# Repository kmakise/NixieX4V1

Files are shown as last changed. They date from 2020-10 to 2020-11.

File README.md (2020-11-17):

# NixieX4V1
四位辉光钟 演示视频：https://www.bilibili.com/video/BV1ni4y1E7YB

# 电源
 12V-5V TPS54331  12V-170V MAX1771

# 控制
 MCU：STM32F103C8T6 REG：74HC595 T：ALJ01 Nixie：QS18-12
 
# 图片




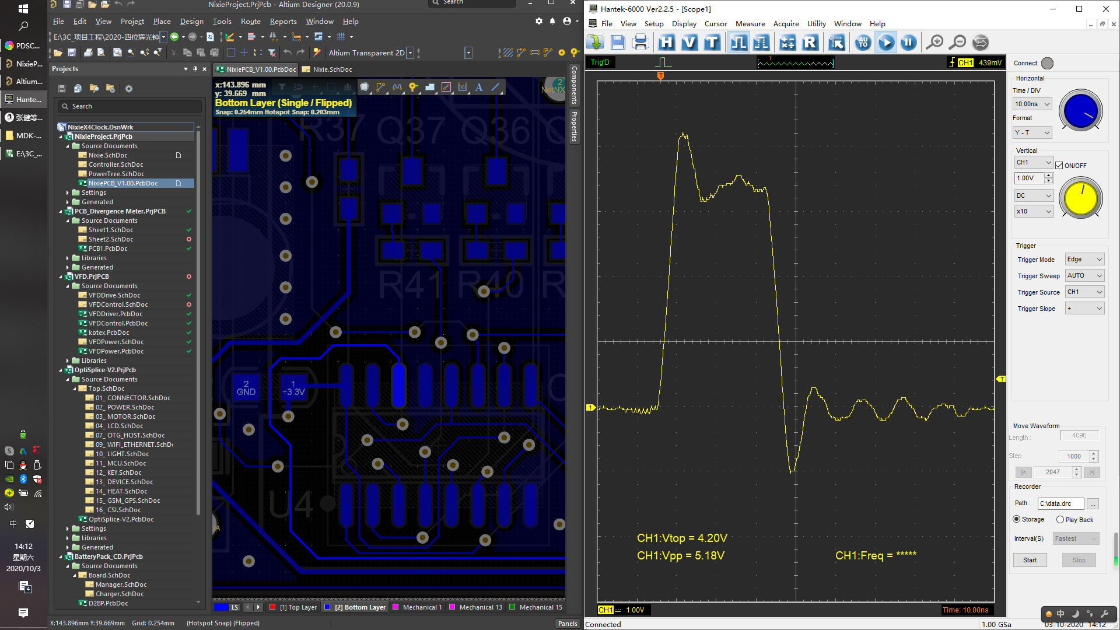
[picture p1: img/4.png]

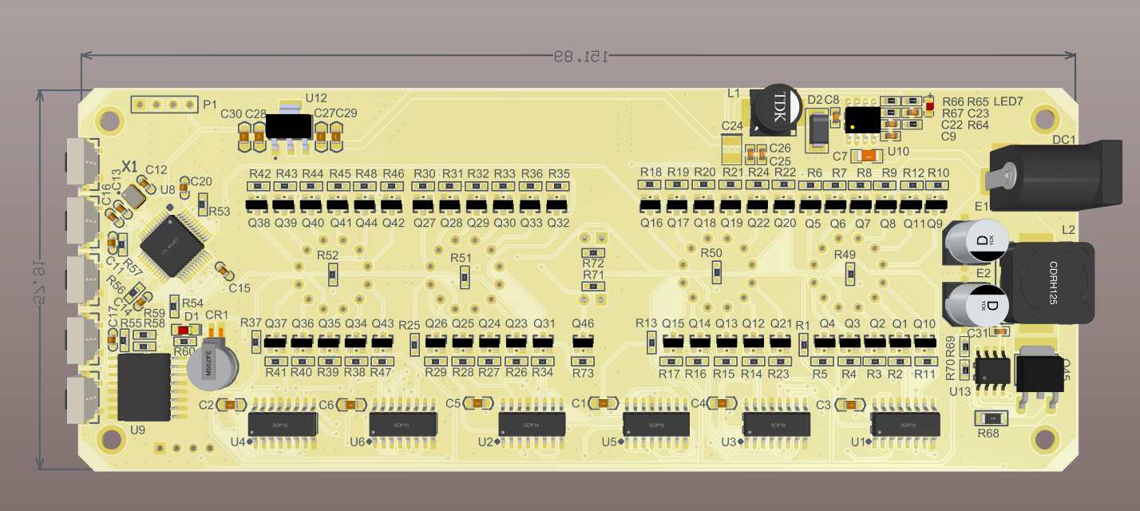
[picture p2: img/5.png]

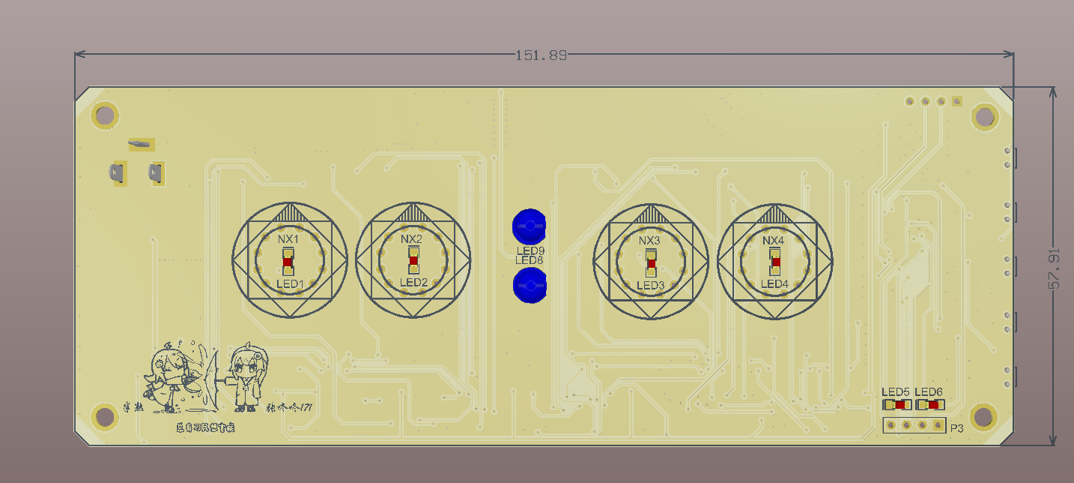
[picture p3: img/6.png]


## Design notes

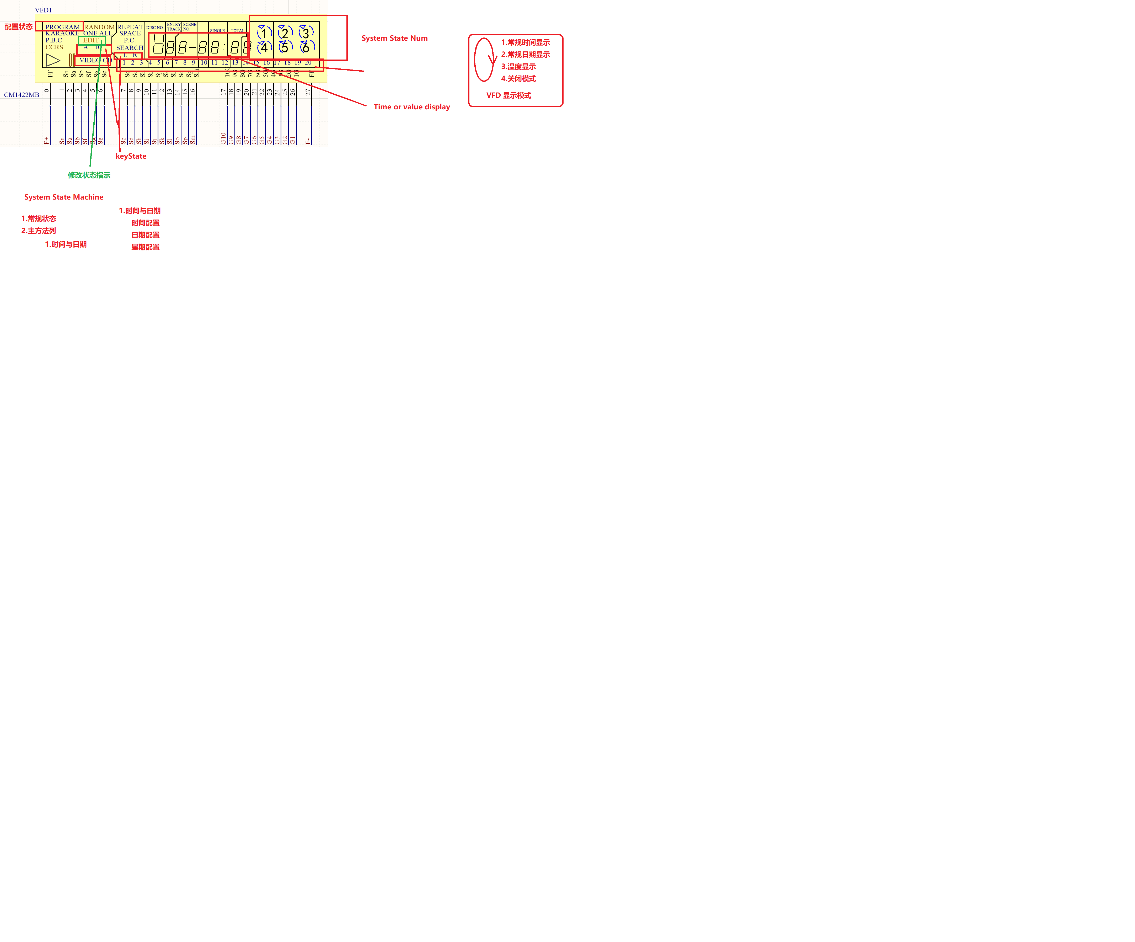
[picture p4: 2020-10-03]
STM32Project/state.png

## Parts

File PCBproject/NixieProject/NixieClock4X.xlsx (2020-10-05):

 |  | NixieClock4X Bom
器件类型 | 型号 | 位号 | 封装 | 数量 | 供应商 | 库存情况
MLCC电容 | 0.1uF/50V | C1, C2, C3, C4, C5, C6 | 0805 | 6
MLCC电容 | 10uF/25V | C7 | 1206 | 1
MLCC电容 | 0.1uF/50V | C8,C11, C14, C15, C16, C17, C20,C31 | 0603 | 8
MLCC电容 | 10nF/50V | C9 | 0603 | 1
MLCC电容 | 22pF/50V | C12, C13 | 0603 | 2
MLCC电容 | 1nF/50V | C22 | 0603 | 1
MLCC电容 | 47pF/50V | C23 | 0603 | 1
钽电解电容 | 10uF/16V | C24 | 3528 | 1
MLCC电容 | 4.7uF/16V | C25, C26 | 0603 | 2
MLCC电容 | 0.1uF/50V | C27, C28 | 0805 | 2
MLCC电容 | 1uF/50V | C29, C30 | 0805 | 2
固态电容 | 100UF/25V | E1 | SMD6.3*7.7 | 1
固态电容 | 10UF/250V | E2 | SMD6.3*7.7 | 1
碳膜电阻 | 1K/5% | R1, R2, R3, R4, R5, R6, R7, R8, R9, R10, R11, R12, R13, R14, R15, R16, R17, R18, R19, R20, R21, R22, R23, R24, R25, R26, R27, R28, R29, R30, R31, R32, R33, R34, R35, R36, R37, R38, R39, R40, R41, R42, R43, R44, R45, R46, R47, R48, R49, R50, R51, R52,R54, R55, R57, R58, R59, R60,R71, R72, R73 | 0603 | 61
碳膜电阻 | 100K/5% | R53, R56 | 0603 | 2
碳膜电阻 | 29.4K/1% | R64 | 0603 | 1
碳膜电阻 | 10K/5% | R65 | 0603 | 1
碳膜电阻 | 10.2K/1% | R66 | 0603 | 1
碳膜电阻 | 1.91K/1% | R67 | 0603 | 1
合金电阻 | 10mΩ/1% | R68 | 1206 | 1
碳膜电阻 | 1.8M/1% | R69 | 0603 | 1
碳膜电阻 | 16k/1% | R70 | 0603 | 1 |  |  |  | 20
 |  |  |  |  |  |  |  | 0.00
一体电感 | 10uH/2A | L1 | 7*7*3mm | 1 |  |  |  | 0.22
一体电感 | 220uH/2A | L2 | 12*12*5mm | 1 |  |  |  | 5.35
 |  |  |  |  |  |  |  | 0.00
二极管 | IN4148 | D1 | SOD-323 | 1 |  |  |  | 0.22
二极管 | SS34 | D2 | DO-214AC-SMA | 1 |  |  |  | 0.6
发光二极管 | 蓝色 | LED1, LED2, LED3, LED4, LED5, LED6,LED7,LED8 | 0805 | 8 |  |  |  | 0.8
发光二极管 | 红色 | LED9 | 0805 | 1 |  |  |  | 0.8
辉光管 | 新光QS18-12 1980 | NX1, NX2, NX3, NX4 | QS18-12 | 4 |  |  |  | 220
高压三极管 NPN | 13001（ALJ01） | Q1, Q2, Q3, Q4, Q5, Q6, Q7, Q8, Q9, Q10, Q11, Q12, Q13, Q14, Q15, Q16, Q17, Q18, Q19, Q20, Q21, Q22, Q23, Q24, Q25, Q26, Q27, Q28, Q29, Q30, Q31, Q32, Q33, Q34, Q35, Q36, Q37, Q38, Q39, Q40, Q41, Q42, Q43, Q44, Q46 | SOT-23 | 45 |  |  |  | 16
场效应管 N-MOS | TK8P65W | Q45 | TO-252 | 1 |  |  |  | 3.80
肖特基二极管 | SR5200 | D3 | SMB | 1
 |  |  |  |  |  |  |  | 0.00
按键 | 两脚点动 | K1, K2, K3, K4, K5 | TSW 3*6*4.3-S-W | 5 |  |  |  | 3
 |  |  |  |  |  |  |  | 0.00
移位寄存器 | 74HC595 | U1, U2, U3, U4, U5, U6 | SOP-16 | 6 |  |  |  | 5
微控制器 | STM32F103C8T6 | U8 | LQFP48 7X7 | 1 |  |  |  | 4
高精度RTC | DS3231 | U9 | SOL-16 | 1 |  |  |  | 3.98
直流开关转换器 | TPS54331 | U10 | SOP-8 | 1 |  |  |  | 1.12
3.3VLDO | LM1117-3.3V | U12 | SOT223 | 1 |  |  |  | 0.22
直流开关转换器 | MAX1771 | U13 | SOP-8 | 1 |  |  |  | 7.30
无源晶振 | 8MHz | X1 | 3225 | 1 |  |  |  | 0.50
纽扣电池 | MS621FE | CR1 | 6.8mm | 1 |  |  |  | 2.00
 |  |  |  |  |  |  |  | 0.00
排针座 NG | 2.54mm | P1,P3 | 2.54 | 2 |  |  |  | 0.5
适配器插座 | DC-005 5.5-2.1MM | DC1 | DC-005 5.5-2.1MM | 1 |  |  |  | 0.5
 |  |  |  |  |  |  | 无
 |  |  |  |  |  |  | 少

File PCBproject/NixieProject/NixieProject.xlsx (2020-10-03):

Designator | Comment | Description | Footprint | LibRef | Quantity
C1, C2, C3, C4, C5, C6 | 0.1uF/50v | 无极性贴片电容 | C 0805 | C | 6
C7 | 10uF/25V | Capacitor | 1206 | CAP1 | 1
C8 | 0.1uF | Capacitor | 0603C | CAP1 | 1
C9 | 10nF | Capacitor | 0603C | CAP1 | 1
C11, C14, C15, C16, C17, C20 | 104 | 无极性贴片电容 | C 0603 | C | 6
C12, C13 | 22pF | 无极性贴片电容 | C 0603 | C | 2
C22 | 1nF | Capacitor | 0603C | CAP1 | 1
C23 | 47pF | Capacitor | 0603C | CAP1 | 1
C24 | CAP-+ | Capacitor | 3528 | CAP-+ | 1
C25, C26 | 4.7uF/16V | Capacitor | 0603C | CAP1 | 2
C27, C28 | 104 | 无极性贴片电容 | C 0805 | C | 2
C29, C30 | 105 | 无极性贴片电容 | C 0805 | C | 2
C31 | 0.1uF/50V | Capacitor | 0603C | CAP1 | 1
CR1 | 电池座 |  | BAT-2P | CR2032 电池座 | 1
D1 | IN4148 |  | 0805D | 二级管 | 1
D2 | SS34 | DIODE LED | DO-214AC-SMA | DIOLED_1 | 1
DC1 | DC |  | DC-005 | DC | 1
E1 | 100UF/25V | 直插固态电容 | CM D(6.3*7.7) | C-CS | 1
E2 | 10UF/250V | 直插固态电容 | CM D(6.3*7.7) | C-CS | 1
K1, K2, K3, K4, K5 | 按键 |  | TSW 3*6*4.3-S-W | 按键 | 5
L1 | 6.8uH |  | L100 | INDUCTOR1_1 | 1
L2 | 220uH | 小功率贴片电感 | CDRH125 | L | 1
LED1, LED2, LED3, LED4, LED5, LED6 | LED |  | 0805D | LED | 6
LED7 | LED3 | DIODE LED | 0603-led | CP_DIOLED | 1
LED8, LED9 | LED |  | LED 5MM-B | LED | 2
NX1, NX2, NX3, NX4 | QS18-12 |  | PCBComponent_1 | QS18-12 | 4
P1 | SWD | Header, 4-Pin | HDR1X4 | Header 4 | 1
P3 | OLED | Header, 4-Pin | HDR1X4 | Header 4 | 1
Q1, Q2, Q3, Q4, Q5, Q6, Q7, Q8, Q9, Q10, Q11, Q12, Q13, Q14, Q15, Q16, Q17, Q18, Q19, Q20, Q21, Q22, Q23, Q24, Q25, Q26, Q27, Q28, Q29, Q30, Q31, Q32, Q33, Q34, Q35, Q36, Q37, Q38, Q39, Q40, Q41, Q42, Q43, Q44, Q46 | NPN |  | SOT-23 | NPN-S8050-SOT-23 | 45
Q45 | TK8P65W | P-channel Enhancement Mode MOSFET | D-PAK | MOSFET-N | 1
R1, R2, R3, R4, R5, R6, R7, R8, R9, R10, R11, R12, R13, R14, R15, R16, R17, R18, R19, R20, R21, R22, R23, R24, R25, R26, R27, R28, R29, R30, R31, R32, R33, R34, R35, R36, R37, R38, R39, R40, R41, R42, R43, R44, R45, R46, R47, R48, R49, R50, R51, R52, R71, R72, R73 | R |  | R 0603 | R | 55
R53, R56 | 100K | 贴片电阻 | R 0603 | R | 2
R54, R55, R57, R58, R59, R60 | 1K | 贴片电阻 | R 0603 | R | 6
R64 | 29.4K |  | 0603 | RES2 | 1
R65 | 10K |  | 0603 | RES2 | 1
R66 | 10.2K |  | 0603 | RES2 | 1
R67 | 1.91K |  | 0603 | RES2 | 1
R68 | 10m |  | R 1206_L | RES2 | 1
R69 | 1.8M |  | 0603 | RES2 | 1
R70 | 16k |  | 0603 | RES2 | 1
U1, U2, U3, U4, U5, U6 | 74HC595 |  | SOP16_M | 74HC595_1 | 6
U8 | STM32F103C8T6 | Flaah:64/RAM:20/IO:36 | LQFP48 7X7_M | STM32F103C8T6 | 1
U9 | DS3231 |  | SOL-16 | DS3231 | 1
U10 | TPS54331 |  | SO08 | TPS54331 | 1
U12 | LM1117 |  | SOT223 | LM1117 | 1
U13 | MAX1771 |  | SOP8 | MAX1771 | 1
X1 | XTAL-24MHz |  | XTAL-3225 | XTAL-SMD | 1

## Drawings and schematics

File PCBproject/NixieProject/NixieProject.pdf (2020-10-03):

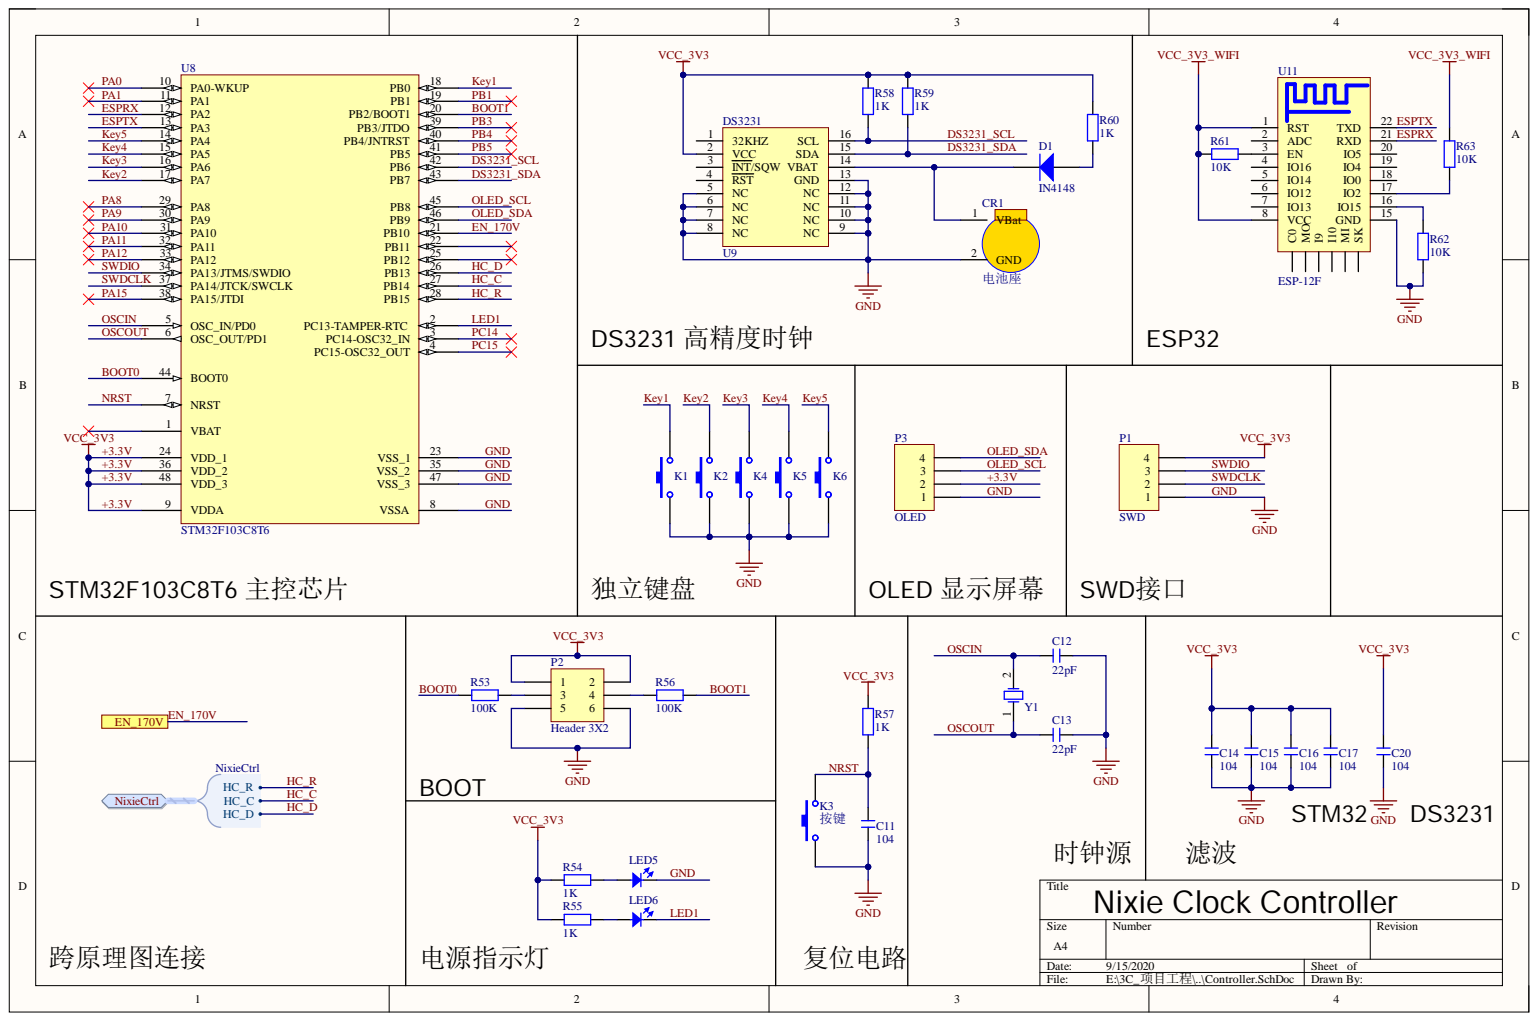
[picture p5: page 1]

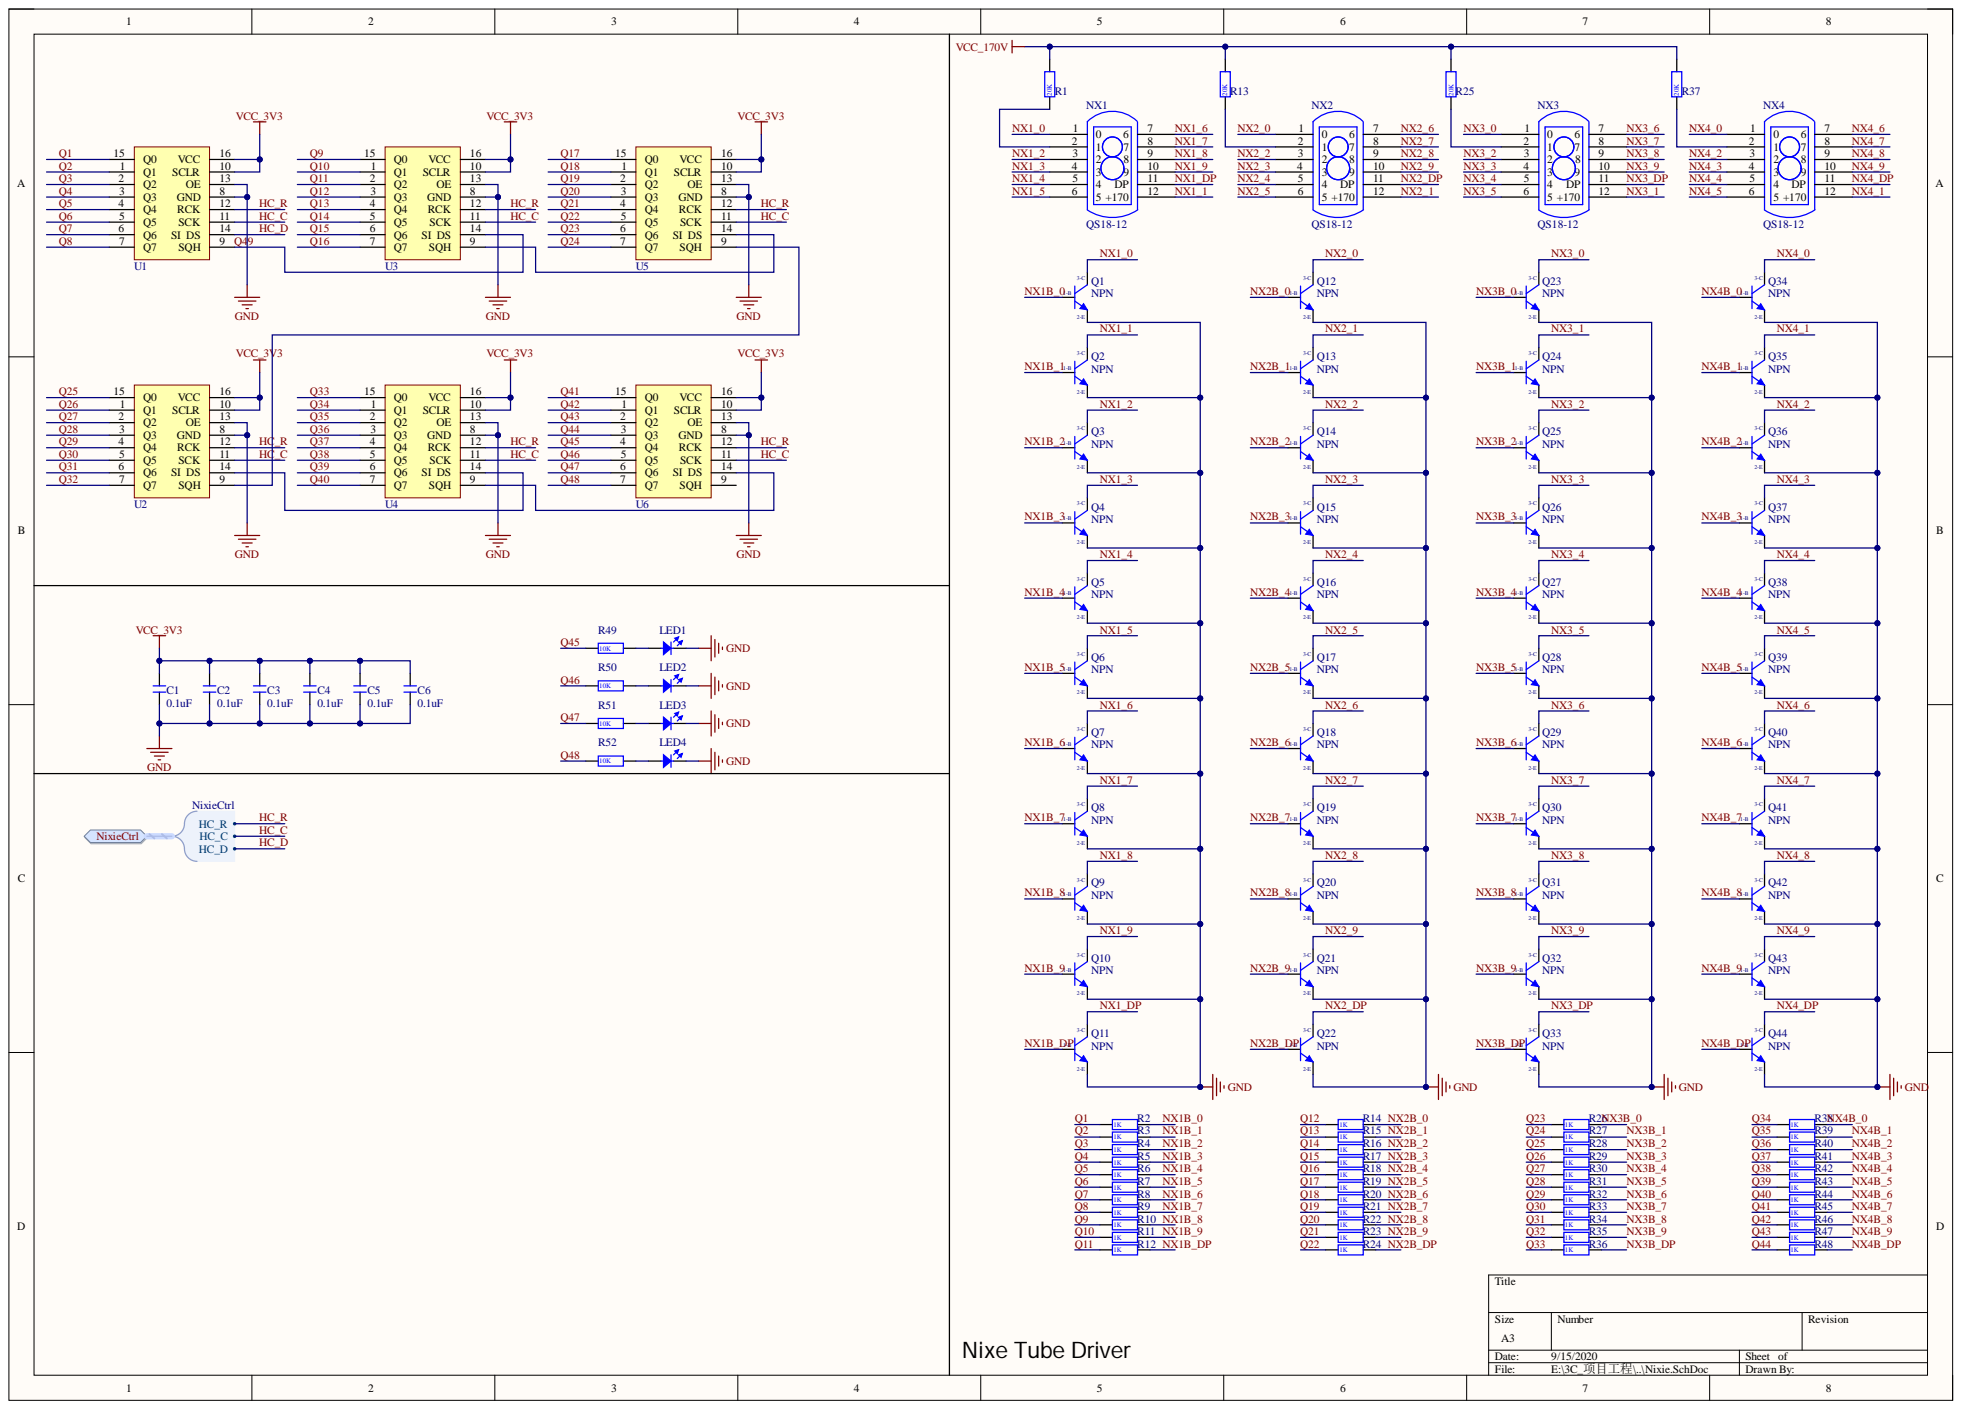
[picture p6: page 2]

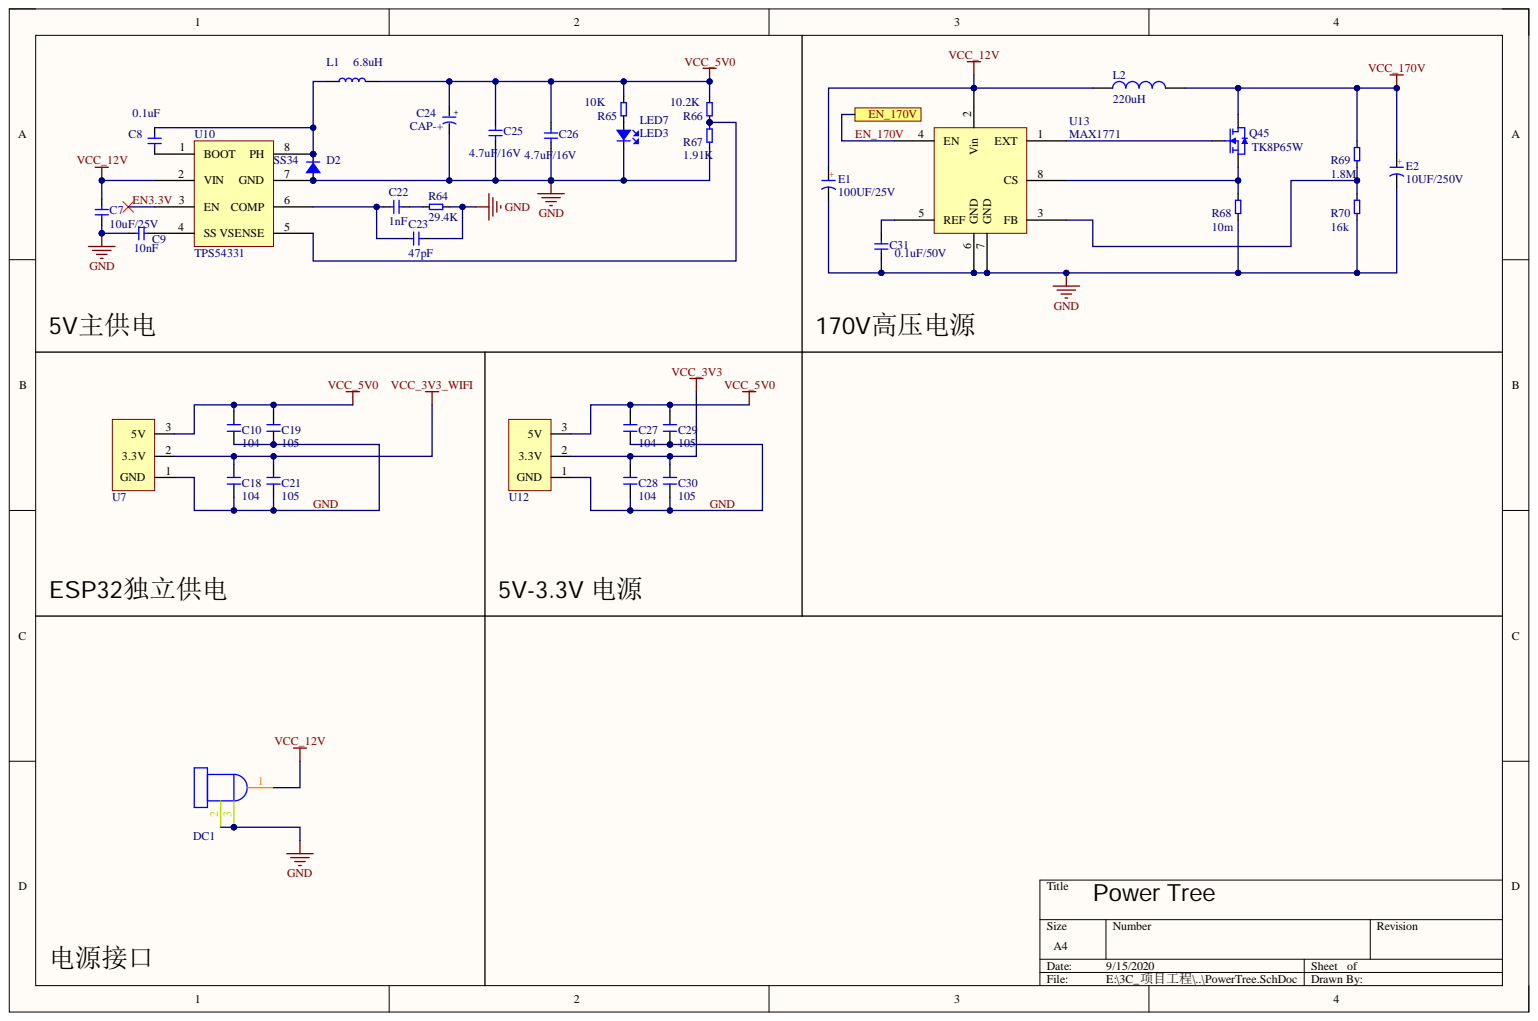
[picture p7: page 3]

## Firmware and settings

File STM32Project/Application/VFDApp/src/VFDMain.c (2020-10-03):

/**
  ******************************************************************************
  * @file    VFDMain.h.c
  * @author  张东
  * @version V1.0.0
  * @date    2019-9-4
	           2020-9-30
  * @brief   四位辉光钟主程序
  ******************************************************************************
  */
#include "main.h"
#include "stm32f1xx_hal.h"
#include "tim.h"
#include "usart.h"

#include "VFDApp.h"

//hardware
#include "oled.h"
#include "DS3231.h"
//#include "VFDDriver.h"

#include "esp8266.h"


/*setup loop and interrupt function*/
void VFDMainSetup(void)
{
	//MCU config
	__HAL_AFIO_REMAP_SWJ_NONJTRST();

//	__HAL_UART_ENABLE_IT(&huart2,UART_IT_RXNE);
//	__HAL_UART_DISABLE_IT(&huart2,UART_IT_IDLE);
	
	
	//hardware init
	OLED_Init();
	OLED_Clear();
	
	//VFDDriverInit();
	
	//esp8266_init();
	
	VFDApp_Setup();
}

void VFDMainLoop(void)
{
	//Test();
	VFDApp_Loop();
}

void VFDMainInterrupt(void)
{
	VFDApp_Interrupt();
}

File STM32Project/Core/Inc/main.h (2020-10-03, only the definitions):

#define LED1_Pin GPIO_PIN_13
#define LED1_GPIO_Port GPIOC
#define ESP_TX_Pin GPIO_PIN_2
#define ESP_TX_GPIO_Port GPIOA
#define ESP_RX_Pin GPIO_PIN_3
#define ESP_RX_GPIO_Port GPIOA
#define key5_Pin GPIO_PIN_4
#define key5_GPIO_Port GPIOA
#define key4_Pin GPIO_PIN_5
#define key4_GPIO_Port GPIOA
#define key3_Pin GPIO_PIN_6
#define key3_GPIO_Port GPIOA
#define key2_Pin GPIO_PIN_7
#define key2_GPIO_Port GPIOA
#define key1_Pin GPIO_PIN_0
#define key1_GPIO_Port GPIOB
#define DAT_Pin GPIO_PIN_13
#define DAT_GPIO_Port GPIOB
#define CLK_Pin GPIO_PIN_14
#define CLK_GPIO_Port GPIOB
#define RCK_Pin GPIO_PIN_15
#define RCK_GPIO_Port GPIOB
#define DS3231_SCL_Pin GPIO_PIN_6
#define DS3231_SCL_GPIO_Port GPIOB
#define DS3231_SDA_Pin GPIO_PIN_7
#define DS3231_SDA_GPIO_Port GPIOB
#define OLED_SCL_Pin GPIO_PIN_8
#define OLED_SCL_GPIO_Port GPIOB
#define OLED_SDA_Pin GPIO_PIN_9
#define OLED_SDA_GPIO_Port GPIOB

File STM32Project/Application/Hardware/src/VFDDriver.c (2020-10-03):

/**
  ******************************************************************************
  * @file    VDDriver.c
  * @author  张东
  * @version V1.0.0
  * @date    2019-9-4
  * @brief   真空荧光表示器 驱动程式
  ******************************************************************************
  */
#include "stm32f1xx_hal.h"
#include "VFDDriver.h"
#include "main.h"

#define NT_DATA(a) GPIOB->BSRR = DAT_Pin << 16 * !a
#define NT_CLK(a)  GPIOB->BSRR = CLK_Pin << 16 * !a
#define NT_OUT(a)  GPIOB->BSRR = RCK_Pin << 16 * !a

//#define NT_DATA(a) HAL_GPIO_WritePin(GPIOB,DAT_Pin,a)
//#define NT_CLK(a)  HAL_GPIO_WritePin(GPIOB,CLK_Pin,a)
//#define NT_OUT(a)  HAL_GPIO_WritePin(GPIOB,RCK_Pin,a)

uint8_t VFDFrameBuffer[10][16];//VFD表示器显示缓冲区
uint8_t VFDLedSateBuffer[6];//控制面板LED状态缓冲区


//VFD 显示段全控
void VFDAllSegment(uint8_t cmd)
{
		for(int i = 0;i < 10;i++)
	{
		for(int j = 0;j < 16;j++)
		{
			VFDFrameBuffer[i][j] = (cmd == 0);
		}
	}
	for(int i = 0;i < 6;i++)
	{
		VFDLedSateBuffer[i] = !(cmd == 0);
	}
}


//显示缓冲区初始化 
void VFDDriverInit(void)
{
	VFDAllSegment(0);
}

//电平输出
void VFDOutputCtrl(uint8_t * num)
{
	uint16_t i;
	for(i = 0;i < 32;i++)
	{
		//data level out
		if(num[31 - i] > 0)
		{
			NT_DATA(1);
		}
		else
		{
			NT_DATA(0);
		}
		//clock out
		NT_CLK(1);
		NT_CLK(0);
	}
	//out put
	NT_OUT(1);
	NT_OUT(0);
}
//VFD 栅极与基底控制
void VFDGateSegmentCtrl(uint8_t gate,uint8_t * segment,uint8_t * led)
{
	uint8_t dat[32] = {1,1,1,1, 1,1,1,1, 1,1,1,1, 1,1,1,1, 1,1,1,1, 1,1,1,1, 1,1,0,0, 0,0,0,0, };
	//栅极控制
	dat[gate + 16] = 0;
	//段显示控制
	for(int i = 0;i < 16;i++)
	{
		dat[i] = segment[i];
	}
	//LED状态控制
	for(int i = 26;i < 32;i++)
	{
		dat[i] = led[i - 26];
	}
	//输出显示
	VFDOutputCtrl(dat);
}

//VFD显示刷新
void VFDDsaplayUpdate(void)
{
	static uint8_t gate = 0;
	VFDGateSegmentCtrl(gate,VFDFrameBuffer[gate],VFDLedSateBuffer);
	gate++;
	if(gate > 9)
	{
		gate = 0;
	}
}

//VFD数码管控制
void VFDNumSegment(uint8_t * num)
{
	//VFD 数码管数值与相应段使能对应表
	const uint8_t VFDNUMSEG[24]={ 
		//"0" "1" "2" "3" "4" "5" "6" "7" "8" "9" "A" "B" "C" 
		0x88,0xDD,0xA4,0x94,0xD1,0x92,0x82,0xDC,0x80,0x90,0xC0,0x83,
		//"D" "E" "F" "H" "L" "n" "u" "P" "o" "-" 熄灭
		0xAA,0x85,0xA2,0xE2,0xC1,0xAB,0xC8,0x89,0xE0,0x87,0xF7,0xFF,  
	};
	//七位数码管段控制
	for(int i = 0;i < 7;i++)
	{
		for(int j = 0;j < 7;j++)
		{
			if((VFDNUMSEG[num[i]] & (0x01 << j)) != 0)
			{
				VFDFrameBuffer[i + 2][j + 1] = 1;
			}
			else
			{
				VFDFrameBuffer[i + 2][j + 1] = 0;
			}
		}
	}
}

//驱动板 led组控制
void LEDGroupCtrl(uint8_t num,uint8_t cmd)
{
	//参数合法性
	if(num < 6 && (cmd == ENABLE || cmd == DISABLE))
	{
		//使能或者失能组内 某一个LED
		VFDLedSateBuffer[num] = cmd;
	}
}

//VFD下方数字组 控制  1-20
void VFDDownNumCtrl(uint8_t num,uint8_t cmd)
{
	const uint8_t VFDNGATE[20] = {1,1,1,2,2,3,4,4,4,5,6,6,7,8,8,8,9,9,9,9,};
	const uint8_t VFDSDATA[20] = {8,9,10,8,9,8,8,9,10,8,8,9,8,8,9,10,4,8,9,10,};
	//参数合法性
	if((0 < num && num < 21) && (cmd == ENABLE || cmd == DISABLE))
	{
		VFDFrameBuffer[VFDNGATE[num - 1]][VFDSDATA[num - 1]] = (cmd == 0);
	}
}
//vfd 右侧显示数字和数字边框的控制 seg 0 1 2 num （） ↑
void RightNumCtrl(uint8_t num,uint8_t seg,uint8_t cmd)
{
	//1 2 3 4 5 6  num ( ) ↑
	const uint8_t RNUMGATE[18] = {8,8,8, 9,9,9, 9,9,9, 8,8,8, 9,9,9, 9,9,9};
	const uint8_t NUMSEG[18] ={0,13,14, 7,5,3, 0,13,14, 11,12,15, 1,2,6, 11,12,15,};
	
	//参数合法性
	if((0 < num && num < 7 && seg < 3) && (cmd == ENABLE || cmd == DISABLE))
	{
		uint8_t pos = (num - 1) * 3 + seg;
		
		VFDFrameBuffer[RNUMGATE[pos]][NUMSEG[pos]] = (cmd == 0);
	}
}

//vfd 数字间隔符号控制
void NumSymbolCtrl(uint8_t num,uint8_t cmd)
{
	if(num == 0)
	{
		VFDFrameBuffer[4][11] = (cmd == 0);//-
	}
	else if(num == 1)
	{
		VFDFrameBuffer[6][11] = (cmd == 0);//:
	}
}

//vfd 关键字高亮显示控制
void WordDisCtrl(VFDWordTypedef num,uint8_t cmd)
{
	const uint8_t VFDWORDSEG[26] = {
		1,2,6,7,9,10,15,12,0,5,3,4,11, 
		15,0,12,1,13,2, 15, 15,0, 15,0, 15, 15
	};
	
	
	if(num <= 12)//gate 0
	{
		VFDFrameBuffer[0][VFDWORDSEG[num]] = (cmd == 0);
	}
	else if(num <= 18)//gate 1
	{
		VFDFrameBuffer[1][VFDWORDSEG[num]] = (cmd == 0);
	}
	else if(num <= 19)//gate 2
	{
		VFDFrameBuffer[2][VFDWORDSEG[num]] = (cmd == 0);
	}
	else if(num <= 21)//gate 3
	{
		VFDFrameBuffer[3][VFDWORDSEG[num]] = (cmd == 0);
	}
	else if(num <= 23)//gate 4
	{
		VFDFrameBuffer[4][VFDWORDSEG[num]] = (cmd == 0);
	}
	else if(num == 24)//gate 6
	{
		VFDFrameBuffer[6][VFDWORDSEG[num]] = (cmd == 0);
	}
	else if(num == 25)//gate 7
	{
		VFDFrameBuffer[7][VFDWORDSEG[num]] = (cmd == 0);
	}
}





/*test function -----------------------------------------------*/
void Test(void)
{
	static uint8_t num = 0;
	uint8_t str[7] = {0,0,0,0,0,0,0};
	
	WordDisCtrl(num,1);
	
	str[5] = num /10;
	str[6] = num %10;
	VFDNumSegment(str);
	
	num ++;
	
	HAL_Delay(1000);
	
	if(num > 25)
	{
		num = 0;
		for(int i = 0;i < 26;i++)
		{
			WordDisCtrl(i,0); 
		}

	}
}

void RightNumTest(void)
{
	static uint8_t num = 0;
	RightNumCtrl(num / 3,num % 3,1);
	num++;

	HAL_Delay(300);
	if(num > 20)
	{
		num = 1;
		for(int i = 0;i < 21;i++)
		{
			RightNumCtrl(i / 3,i % 3,0);
		}
	}
}

void DownNumTest(void)
{
	static uint8_t num = 2;
	
	VFDDownNumCtrl(num++,0);
	VFDDownNumCtrl(num,1);
	if(num > 20)
	{
		num = 0;
	}
	
	HAL_Delay(300);
}


void NumTest(void)
{
	static uint32_t dat = 0;
	uint8_t num[7];
	num[0] = dat/1000000%10;
	num[1] = dat/100000%10;
	num[2] = dat/10000%10;
	num[3] = dat/1000%10;
	num[4] = dat/100%10;
	num[5] = dat/10%10;
	num[6] = dat%10;
	
	if(dat > 9999999)
	{
		dat = 0;
	}
	dat++;
	VFDNumSegment(num);
	//VFDFrameBuffer[2][3] = 0;
}


void SegTest(void)
{
	uint8_t seg[16] = {
		1,0,1,1, 1,1,1,1, 1,1,1,1, 1,1,1,1, 
	};
	
	uint8_t led[6] = {
		1,1,1,1,1,0
	};
	
	VFDGateSegmentCtrl(3,seg,led);
}

//VFD 显示测试
void DisTest(void)
{
	static int num = 0;
	uint8_t dat[32];
	
	for(int i = 0;i< 32;i++)
	{
		dat[i] = 1;
	}
	
	for(int i = 16;i < 26;i++)
	{
		dat[i] = 0;
	}
	dat[num++] = 0;
	if(num > 15)num = 0;
	VFDOutputCtrl(dat);
	HAL_Delay(100);
}

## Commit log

2020-10-03 Start
    开始
    [Controller.SchDoc, Nixie.SchDoc, NixieClock4X.xlsx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]
2020-10-05 更新物料清单 删除 历史
    [NixieClock4X.xlsx]

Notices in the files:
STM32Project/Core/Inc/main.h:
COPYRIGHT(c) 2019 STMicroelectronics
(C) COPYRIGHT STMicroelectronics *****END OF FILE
